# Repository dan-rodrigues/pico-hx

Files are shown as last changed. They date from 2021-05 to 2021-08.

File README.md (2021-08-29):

# PicoHX

This is an FPGA board that combines an iCE40 HX FPGA with the Raspberry Pi Pico. The Pico can program the FPGA over USB using a script included in this repo and then interact with it using GPIO.

## KiCad rendering

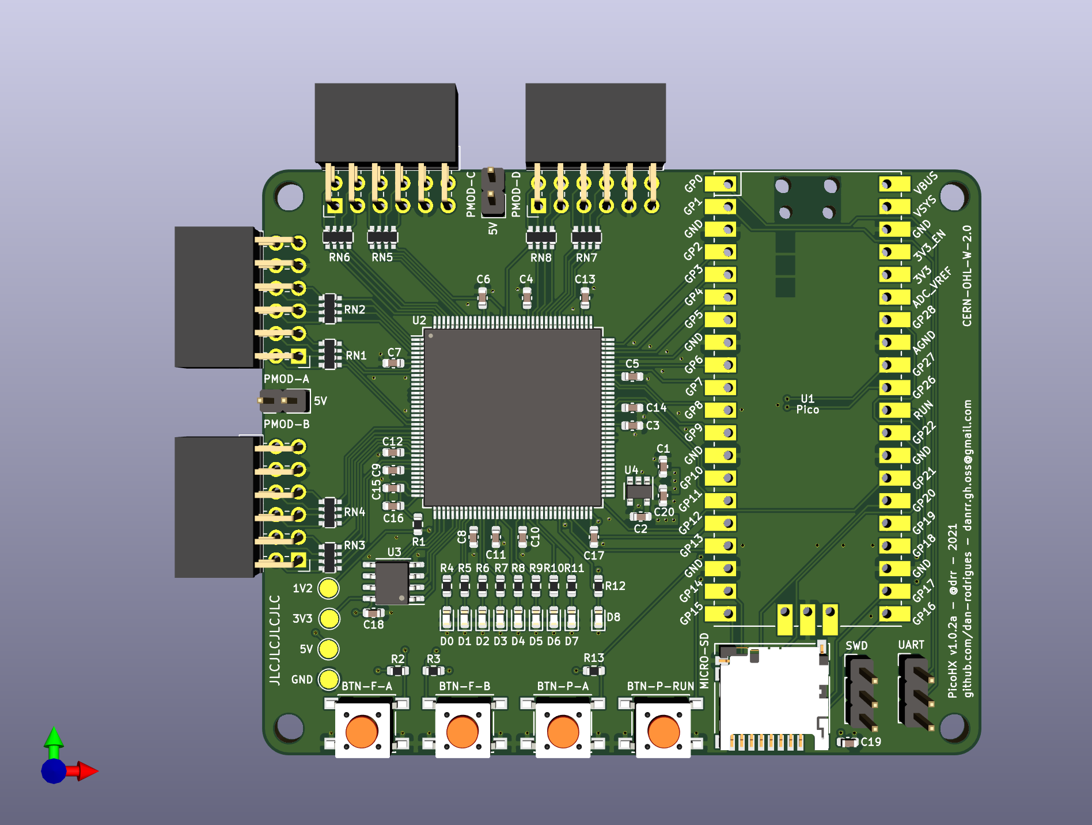
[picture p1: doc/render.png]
PCB rendering


## DVI Demo

Pictured is an included DVI demo. First, the RP2040 was programmed with the USB software which then exposes a USB programmer device to the host. Then, the FPGA configuration containing the DVI test pattern config was uploaded from the host to the RP2040, which then programmed the FPGA, which then displayed the test pattern on screen. [This DVI PMOD](https://1bitsquared.com/collections/fpga/products/pmod-digital-video-interface) was used.

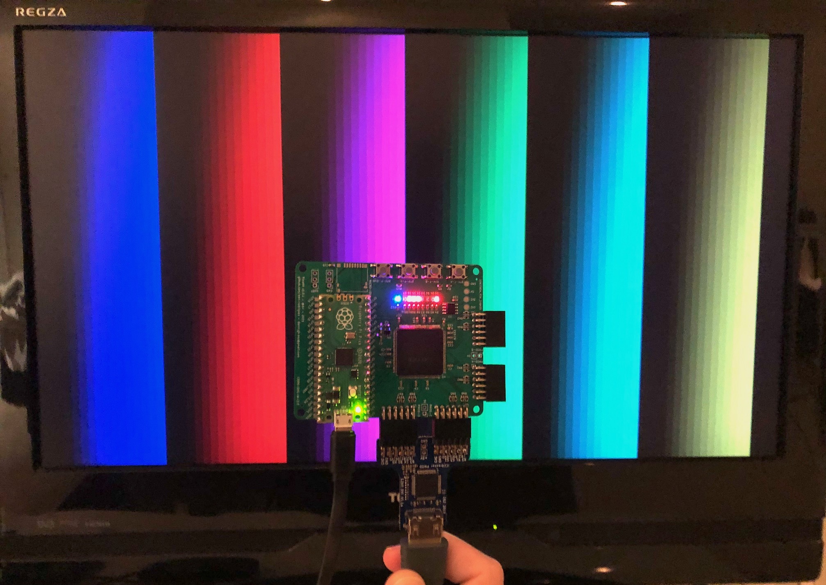
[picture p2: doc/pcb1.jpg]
PCB DVI demo


## Features

* iCE40 HX FPGA (TQFP144, 1k pinout assumed)
* 10 Pico GPIOs connected to FPGA
    * 2 are connected to `GBIN` inputs
* 4x PMODs in a 2x double-PMOD arrangement
* 8x user LEDs for FPGA
* 1x CDONE LED
* 2x users buttons for FPGA
* 1x user button for Pico
* `RUN` button for Pico
* Headers for Pico SWD and hardware UART
* Footprint for QSPI PSRAM or flash
* Micro SD card slot

## Design

### Programming

All iCE40 configuration pins are routed to the RP2040 GPIO so the details of how or when it is programmed are up to the software. The included software in this repo will make the Pico present itself is a USB device with these interfaces:

* Vendor programmer interface: This is how the user can program the iCE40 at any time over USB, using the included [picoprog.py](scripts/picoprog.py) script.
* CDC UART: This UART is separate to the hardware UART that is available on the dedicated pin header. By default, `stdout` is sent to the CDC UART for convenience.

### FPGA clock

The pico exposes one pin that can directly output a clock from one of its PLLs with an optional divider. In the demo software, the USB PLL (48MHz) is divided by 4 to output a 12MHz clock for the FPGA. On the FPGA side, the `GBIN5` pin is used for clock input so that the  `SB_PLL40_2F_PAD` can be used.

### Power

There is only a 1.2v regulator on the board as the Pico provides a 3.3v output. The `2V5_VPP` input is tied to 3.3v as the NVCM isn't used in this project.

### PIO support

The 10 GPIOs connected to the FPGA and 4 GPIOs connected to the SD card slot are in consecutive order, so PIO can be used.

## Demo

A demo that displays several test patterns controlled by BTN-A and blinks the LEDs in succession can be found in [rtl/demo](rtl/demo).

```
cd rtl/demo
make prog
```
 
## Usage

### Building Pico software

It's assumed that the [pico-sdk](https://github.com/raspberrypi/pico-sdk) is installed and the required environment variables are set.

```
cd software
mkdir build
cd build
cmake ..
make
```

The software can then be flashed using `picotool` for example. Default behaviour of the software is to immediately flash the iCE40 with an included bitstream that runs a counter with output to the 8 user LEDs.

### Programming iCE40 bitstream

It's assumed that the OSS FPGA toolchain is installed which includes [yosys](https://github.com/YosysHQ/yosys) and [nextpnr-ice40](https://github.com/YosysHQ/nextpnr).

After the Pico software is flashed, it's ready to program the iCE40 using a custom USB driver script. The script is written in Python3 and requires [pyusb](https://github.com/pyusb/pyusb).

```
pip3 install pyusb
```

It can then be programmed with similar usage to [iceprog](https://github.com/YosysHQ/icestorm/tree/master/iceprog). The programmer script is [picoprog.py](scripts/picoprog.py).

```
./picoprog.py bitstream.bit
```

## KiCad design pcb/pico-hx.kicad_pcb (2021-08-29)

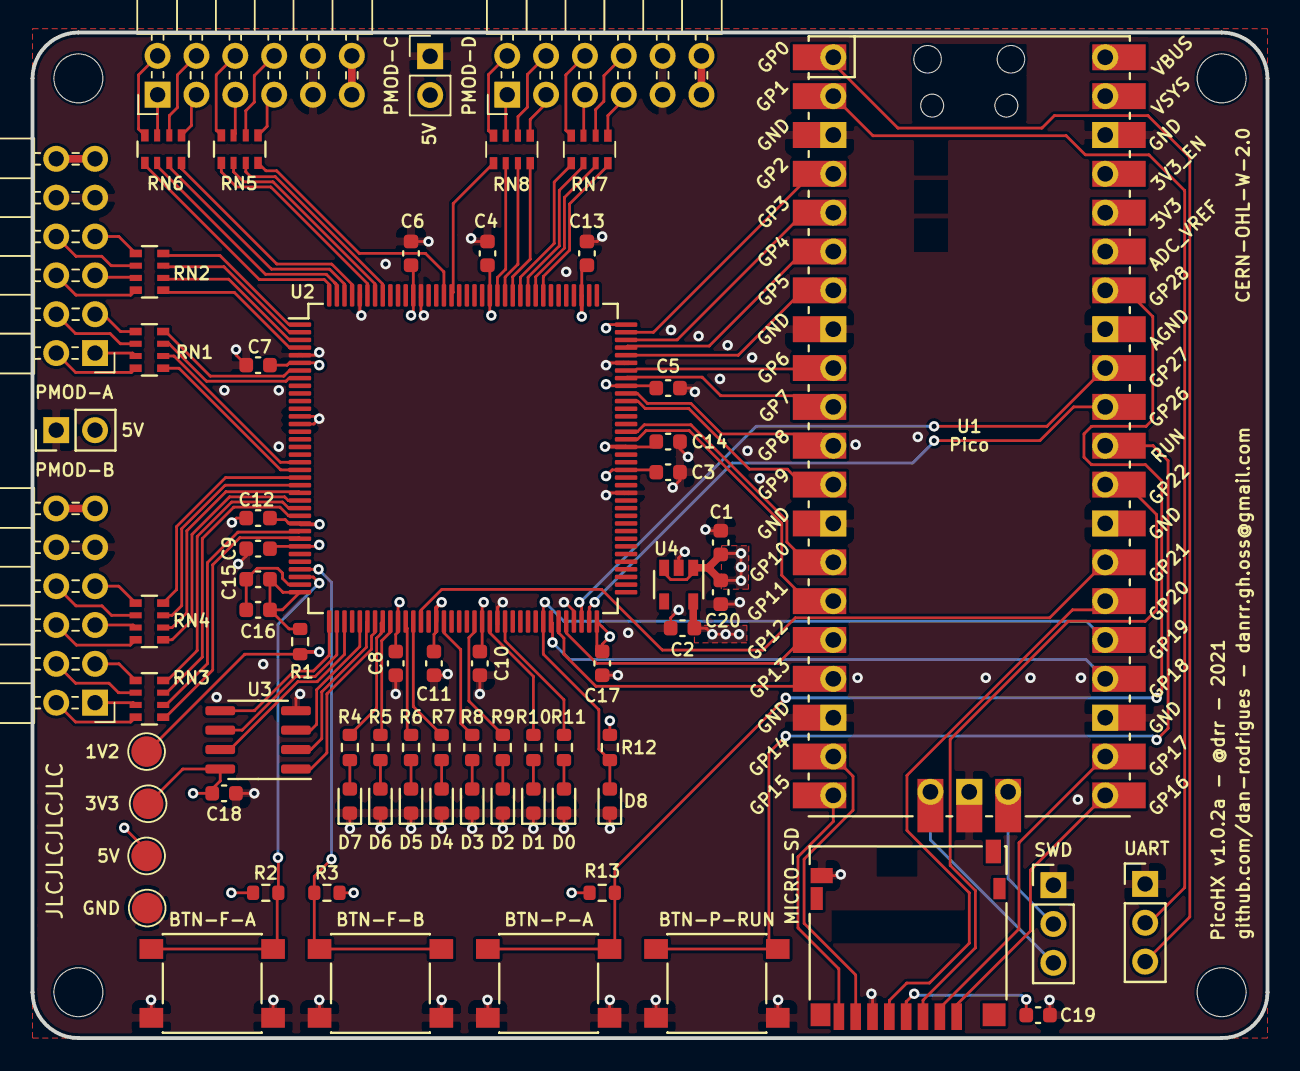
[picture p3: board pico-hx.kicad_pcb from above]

Board: 4 copper layers, 80.7 x 65.8 mm, 75 parts (0 on the bottom side), 123 nets.

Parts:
C1, C2: 1uF; C_0603_1608Metric
C3, C4, C5, C6, C7, C8, C9, C10, C11, C12, C13, C14, C15, C17, C18: 100nF; C_0603_1608Metric
C16, C19: 10uF; C_0603_1608Metric
C20: 10nF; C_0603_1608Metric
D0, D1, D2, D3, D4, D5, D6, D7: LED; LED_0603_1608Metric
D8: LED_B; LED_0603_1608Metric
H1, H2, H3, H4: MountingHole; MountingHole_3.2mm_M3_DIN965
J1: PMOD_A; PMOD_Double_Mirrored
J2: PMOD_B; PMOD_Double_Mirrored
J3: Micro_SD; microSD_HC_Hirose_DM3D-SF
J4: PMOD_C; PMOD_Double_Mirrored
J5: PMOD_D; PMOD_Double_Mirrored
J6: UART; PinHeader_1x03_P2.54mm_Vertical
J7: RP_SWD; PinHeader_1x03_P2.54mm_Vertical
J8: 5V_AB; PinHeader_1x02_P2.54mm_Vertical
J9: 5V_CD; PinHeader_1x02_P2.54mm_Vertical
R1: 100R; R_0603_1608Metric
R2, R3, R13: 10k; R_0603_1608Metric
R4, R5, R6, R7, R8, R9, R10, R11, R12: 2.2k; R_0603_1608Metric
RN1, RN2, RN3, RN4, RN5, RN6, RN7, RN8: 33R; R_Array_Convex_4x0603
SW1: RUN; SW_SPST_PTS645
SW2: BTN_A; SW_SPST_PTS645
SW3: BTN_B; SW_SPST_PTS645
SW4: BTN_R; SW_SPST_PTS645
TP1: TP_1V2; TestPoint_Pad_D2.0mm
TP2: TP_3V3; TestPoint_Pad_D2.0mm
TP3: TP_5V; TestPoint_Pad_D2.0mm
TP4: TP_GND; TestPoint_Pad_D2.0mm
U1: Pico; RPi_Pico_SMD_TH
U2: ICE40HX1K-TQ144; TQFP-144_20x20mm_P0.5mm
U3: PSRAM; SOIC-8_3.9x4.9mm_P1.27mm
U4: MIC5504-1.2YM5; SOT-23-5

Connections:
+1V2: C2.1, C11.1, C12.1, C13.1, C14.1, R1.1, TP1.1, U2.27, U2.51, U2.92, U2.111, U4.5
+3V3: C3.1, C4.1, C5.1, C6.1, C7.1, C8.1, C9.1, C10.1, C17.1, C18.1, C19.1, J1.6, J1.12, J2.6, J2.12, J3.4, J4.6, J4.12, J5.6, J5.12, R2.1, R3.1, R12.1, R13.1, TP2.1, U1.36, U2.6, U2.30, U2.46, U2.57, U2.72, U2.89, U2.100, U2.108, U2.123, U2.133, U3.8
+5V: C1.1, C20.1, J8.2, J9.2, TP3.1, U1.40, U4.1, U4.3
/BTN_A: R2.2, SW2.1, U2.34
/BTN_B: R3.2, SW3.1, U2.33
/BTN_P: R13.2, SW4.1, U1.34
/FPGA_CDONE: D8.2, R12.2, U1.25, U2.65
/FPGA_CLK: U1.27, U2.49
/FPGA_GNDPLL: C15.2, C16.2, U2.35
/FPGA_RPIO_0: U1.4, U2.107
/FPGA_RPIO_1: U1.5, U2.106
/FPGA_RPIO_2: U1.6, U2.105
/FPGA_RPIO_3: U1.7, U2.104
/FPGA_RPIO_4: U1.9, U2.102
/FPGA_RPIO_5: U1.10, U2.101
/FPGA_RPIO_6: U1.11, U2.99
/FPGA_RPIO_7: U1.12, U2.98
/FPGA_RPIO_S0: U1.14, U2.94
/FPGA_RPIO_S1: U1.15, U2.93
/FPGA_SCK: U1.32, U2.70
/FPGA_SDI: U1.16, U2.68
/FPGA_SDO: U1.17, U2.67
/FPGA_SS: U1.31, U2.71
/FPGA_VCCPLL: C15.1, C16.1, R1.2, U2.36
/LED_0: R11.1, U2.60
/LED_1: R10.1, U2.58
/LED_2: R9.1, U2.56
/LED_3: R8.1, U2.52
/LED_4: R7.1, U2.48
/LED_5: R6.1, U2.47
/LED_6: R5.1, U2.45
/LED_7: R4.1, U2.44
/PMOD_A1: RN1.6, U2.19
/PMOD_A2: RN1.8, U2.7
/PMOD_A3: RN2.6, U2.3
/PMOD_A4: RN2.8, U2.1
/PMOD_A7: RN1.5, U2.20
/PMOD_A8: RN1.7, U2.8
/PMOD_A9: RN2.5, U2.4
/PMOD_A10: RN2.7, U2.2
/PMOD_B1: RN3.6, U2.28
/PMOD_B2: RN3.8, U2.25
/PMOD_B3: RN4.6, U2.23
/PMOD_B4: RN4.8, U2.21
/PMOD_B7: RN3.5, U2.29
/PMOD_B8: RN3.7, U2.26
/PMOD_B9: RN4.5, U2.24
/PMOD_B10: RN4.7, U2.22
/PMOD_C1: RN6.6, U2.143
/PMOD_C2: RN6.8, U2.141
/PMOD_C3: RN5.6, U2.138
/PMOD_C4: RN5.8, U2.129
/PMOD_C7: RN6.5, U2.144
/PMOD_C8: RN6.7, U2.142
/PMOD_C9: RN5.5, U2.139
/PMOD_C10: RN5.7, U2.137
/PMOD_D1: RN8.6, U2.122
/PMOD_D2: RN8.8, U2.120
/PMOD_D3: RN7.6, U2.118
/PMOD_D4: RN7.8, U2.116
/PMOD_D7: RN8.5, U2.128
/PMOD_D8: RN8.7, U2.121
/PMOD_D9: RN7.5, U2.119
/PMOD_D10: RN7.7, U2.117
/PSRAM_SCK: U2.38, U3.6
/PSRAM_SI: U2.37, U3.5
/PSRAM_SIO2: U2.41, U3.3
/PSRAM_SIO3: U2.39, U3.7
/PSRAM_SO: U2.42, U3.2
/RP_SWCLK: J7.3, U1.41
/RP_SWDIO: J7.2, U1.43
/SD_CLK: J3.5, U1.26
/SD_CMD: J3.3, U1.29
/SD_DAT0: J3.7, U1.19
/SD_DAT1: J3.8, U1.20
/SD_DAT2: J3.1, U1.21
/SD_DAT3: J3.2, U1.22
/UART_RX: J6.2, U1.2
/UART_TX: J6.3, U1.1
/~FPGA_CRESET: U1.24, U2.66
/~PSRAM_CS: U2.43, U3.1
GND: C1.2, C2.2, C3.2, C4.2, C5.2, C6.2, C7.2, C8.2, C9.2, C10.2, C11.2, C12.2, C13.2, C14.2, C17.2, C18.2, C19.2, C20.2, D0.1, D1.1, D2.1, D3.1, D4.1, D5.1, D6.1, D7.1, D8.1, J1.5, J1.11, J2.5, J2.11, J3.6, J3.9, J4.5, J4.11, J5.5, J5.11, J6.1, J7.1, J8.1, J9.1, SW1.2, SW2.2, SW3.2, SW4.2, TP4.1, U1.3, U1.8, U1.13, U1.18, U1.23, U1.28, U1.33, U1.38, U1.42, U2.5, U2.13, U2.14, U2.59, U2.69, U2.86, U2.103, U2.132, U2.140, U3.4, U4.2
unnamed: D0.2, R11.2
unnamed: D1.2, R10.2
unnamed: D2.2, R9.2
unnamed: D3.2, R8.2
unnamed: D4.2, R7.2
unnamed: D5.2, R6.2
unnamed: D6.2, R5.2
unnamed: D7.2, R4.2
unnamed: J1.1, RN1.3
unnamed: J1.2, RN1.1
unnamed: J1.3, RN2.3
unnamed: J1.4, RN2.1
unnamed: J1.7, RN1.4
unnamed: J1.8, RN1.2
unnamed: J1.9, RN2.4
unnamed: J1.10, RN2.2
unnamed: J2.1, RN3.3
unnamed: J2.2, RN3.1
unnamed: J2.3, RN4.3
unnamed: J2.4, RN4.1
unnamed: J2.7, RN3.4
unnamed: J2.8, RN3.2
unnamed: J2.9, RN4.4
unnamed: J2.10, RN4.2
unnamed: J4.1, RN6.3
unnamed: J4.2, RN6.1
unnamed: J4.3, RN5.3
unnamed: J4.4, RN5.1
unnamed: J4.7, RN6.4
unnamed: J4.8, RN6.2
unnamed: J4.9, RN5.4
unnamed: J4.10, RN5.2
unnamed: J5.1, RN8.3
unnamed: J5.2, RN8.1
unnamed: J5.3, RN7.3
unnamed: J5.4, RN7.1
unnamed: J5.7, RN8.4
unnamed: J5.8, RN8.2
unnamed: J5.9, RN7.4
unnamed: J5.10, RN7.2
unnamed: SW1.1, U1.30

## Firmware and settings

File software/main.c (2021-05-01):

// main.c
//
// Copyright (C) 2021 Dan Rodrigues <danrr.gh.oss@gmail.com>
//
// SPDX-License-Identifier: MIT

#include "pico/stdlib.h"
#include "hardware/clocks.h"

#include "phx_gpio.h"
#include "tusb.h"
#include "get_serial.h"
#include "usb_uart.h"
#include "usb_programmer.h"
#include "fpga_spi.h"

#include "default_bitstream.h"

int main() {
#ifndef PICO_DEFAULT_LED_PIN
#warning blink example requires a board with a regular LED
#else
    // Default to Pico LED on
    const uint LED_PIN = PICO_DEFAULT_LED_PIN;
    gpio_init(LED_PIN);
    gpio_set_dir(LED_PIN, GPIO_OUT);
    gpio_put(LED_PIN, 1);

    // 48MHz / 4 = 12MHz clock output to FPGA
    const uint usb_clk = 48;
    const uint target_clk = 12;
    const uint clk_divisor = usb_clk / target_clk;
    clock_gpio_init(
        PHX_GPIO_FPGA_CLK_IN,
        CLOCKS_CLK_GPOUT0_CTRL_AUXSRC_VALUE_CLKSRC_PLL_USB,
        clk_divisor
    );

    // Program the included default bitstream
    // This can be replaced later at any time with the USB programmer script
    fpga_upload_bitstream(default_bitstream, default_bitstream_len);

    // USB init before entering main loop
    tusb_init();
    stdio_usb_init();

    while (true) {
        tud_task();
        usb_prog_task();
    }
#endif
}

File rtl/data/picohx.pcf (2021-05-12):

# Clock from RP2040

set_io clk_in 49

# LEDs

set_io led[0] 60
set_io led[1] 58
set_io led[2] 56
set_io led[3] 52
set_io led[4] 48
set_io led[5] 47
set_io led[6] 45
set_io led[7] 44

# Buttons

set_io btn_a 34
set_io btn_b 33

# PSRAM / Flash

set_io psram_sck 38
set_io psram_csn 43
set_io psram_io[0] 37
set_io psram_io[1] 42
set_io psram_io[2] 41
set_io psram_io[3] 39

# RP2040 GPIO

set_io rp_io[0] 107
set_io rp_io[1] 106
set_io rp_io[2] 105
set_io rp_io[3] 104
set_io rp_io[4] 102
set_io rp_io[5] 101
set_io rp_io[6] 99
set_io rp_io[7] 98

set_io rp_sio[0] 94
set_io rp_sio[1] 93

# PMOD-A

set_io pmod_a1 19
set_io pmod_a2 7
set_io pmod_a3 3
set_io pmod_a4 1
set_io pmod_a7 20
set_io pmod_a8 8
set_io pmod_a9 4
set_io pmod_a10 2

# PMOD-B

set_io pmod_b1 28
set_io pmod_b2 25
set_io pmod_b3 23
set_io pmod_b4 21
set_io pmod_b7 29
set_io pmod_b8 26
set_io pmod_b9 24
set_io pmod_b10 22

# PMOD-C

set_io pmod_c1 143
set_io pmod_c2 141
set_io pmod_c3 138
set_io pmod_c4 129
set_io pmod_c7 144
set_io pmod_c8 142
set_io pmod_c9 139
set_io pmod_c10 137

# PMOD-D

set_io pmod_d1 122
set_io pmod_d2 120
set_io pmod_d3 118
set_io pmod_d4 116
set_io pmod_d7 128
set_io pmod_d8 121
set_io pmod_d9 119
set_io pmod_d10 117

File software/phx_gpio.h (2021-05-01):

// phx_gpio.h
//
// Copyright (C) 2021 Dan Rodrigues <danrr.gh.oss@gmail.com>
//
// SPDX-License-Identifier: MIT

#define PHX_GPIO_FPGA_SDI 12
#define PHX_GPIO_FPGA_SDO 13
#define PHX_GPIO_FPGA_CRESET 18
#define PHX_GPIO_FPGA_CDONE 19
#define PHX_GPIO_FPGA_CLK_IN 21
#define PHX_GPIO_FPGA_SS 26
#define PHX_GPIO_FPGA_SCK 27

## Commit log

2021-05-01 Restore repo
    [pico-hx.kicad_pcb, pico-hx.sch]
2021-05-03 scripts: correct header with filename
    [picoprog.py]
2021-05-07 doc: add partial PCB assembly photo
2021-05-12 pcb: reverse LED order to be more intuitive
    Previously the LSB was on the right and the MSB was on left.
    Outputting an 8bit value for example would be confusing if interpreting it as a binary representation.
    [pico-hx.kicad_pcb, pico-hx.sch]
2021-08-29 pcb: add copper-keepout for SD card connector
    [pico-hx.kicad_pcb]
2021-08-29 doc: remove "WIP" qualifier since board was tested

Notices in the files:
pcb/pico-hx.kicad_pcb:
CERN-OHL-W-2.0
